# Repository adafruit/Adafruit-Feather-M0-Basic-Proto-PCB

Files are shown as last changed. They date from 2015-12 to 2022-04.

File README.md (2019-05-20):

## Adafruit Feather M0 Basic Proto PCB
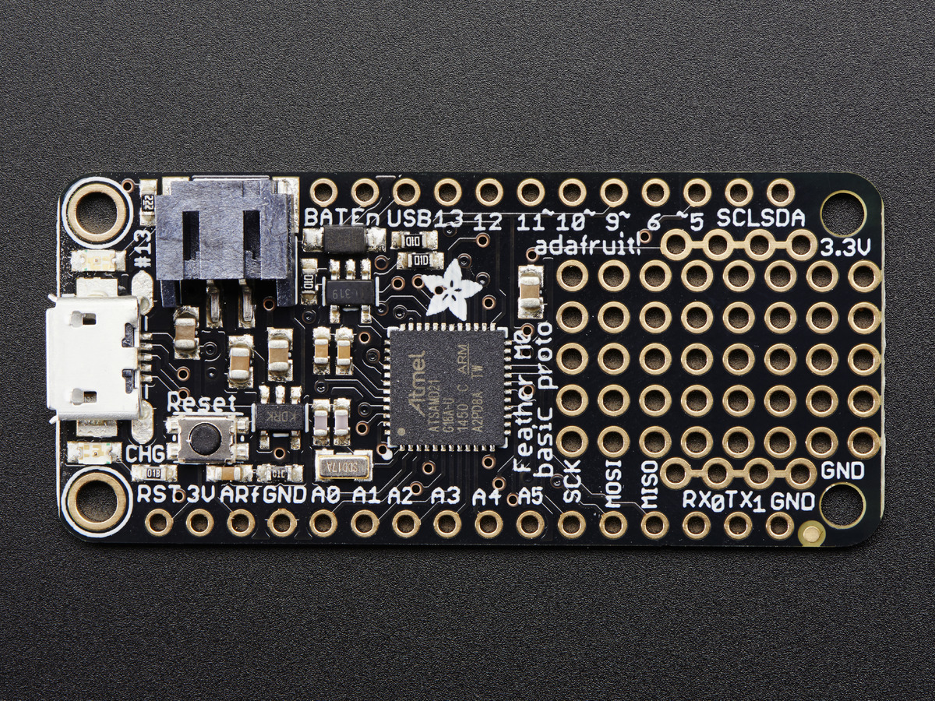
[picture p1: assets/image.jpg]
<a href="http://www.adafruit.com/products/2772"><br/>
Click here to purchase one from the Adafruit shop</a>

The Feather M0 has an ATSAMD21G18 ARM Cortex M0 processor, clocked at 48 MHz and at 3.3V logic, the same one used in the Arduino Zero. This chip has a whopping 256K of FLASH (8x more than the Atmega328 or 32u4) and 32K of RAM (16x as much)! This chip comes with built in USB so it has USB-to-Serial program & debug capability built in with no need for an FTDI-like chip.

To make it easy to use for portable projects, we added a connector for any of our 3.7V Lithium polymer batteries and built in battery charging. You don't need a battery, it will run just fine straight from the micro USB connector. But, if you do have a battery, you can take it on the go, then plug in the USB to recharge. The Feather will automatically switch over to USB power when its available. We also tied the battery thru a divider to an analog pin, so you can measure and monitor the battery voltage to detect when you need a recharge.

PCB files for the Adafruit Feather M0 Basic Proto. The format is EagleCAD schematic and board layout
- https://www.adafruit.com/product/2772

### License

Adafruit invests time and resources providing this open source design, please support Adafruit and open-source hardware by purchasing products from [Adafruit](https://www.adafruit.com)!

All text above must be included in any redistribution

Designed by Limor Fried/Ladyada for Adafruit Industries.
Creative Commons Attribution/Share-Alike, all text above must be included in any redistribution. 
See license.txt for additional information.

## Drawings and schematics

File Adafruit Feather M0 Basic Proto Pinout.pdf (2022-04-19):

# Adafruit Feather M0 Basic Proto

# https://www.adafruit.com/products/2772

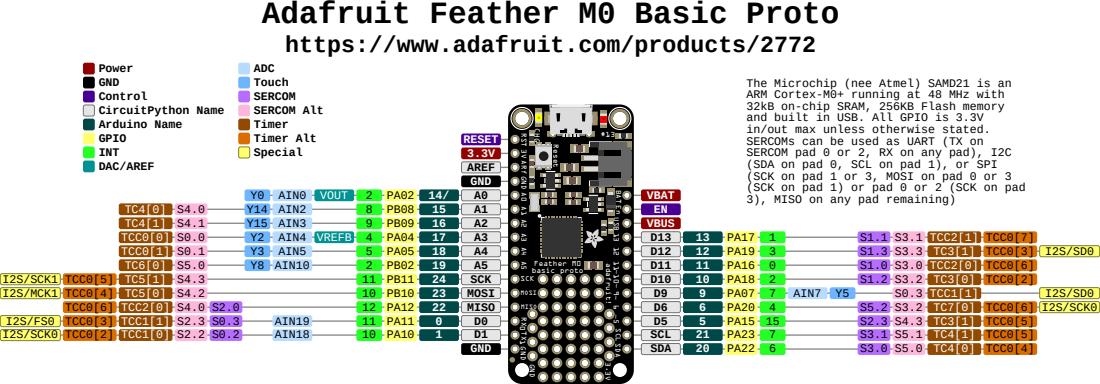
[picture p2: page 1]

The Microchip (nee Atmel) SAMD21 is an
ARM Cortex-M0+ running at 48 MHz with
32kB on-chip SRAM, 256KB Flash memory
and built in USB. All GPIO is 3.3V
in/out max unless otherwise stated.
SERCOMs can be used as UART (TX on
SERCOM pad 0 or 2, RX on any pad), I2C
(SDA on pad 0, SCL on pad 1), or SPI
(SCK on pad 1 or 3, MOSI on pad 0 or 3
(SCK on pad 1) or pad 0 or 2 (SCK on pad
3), MISO on any pad remaining)

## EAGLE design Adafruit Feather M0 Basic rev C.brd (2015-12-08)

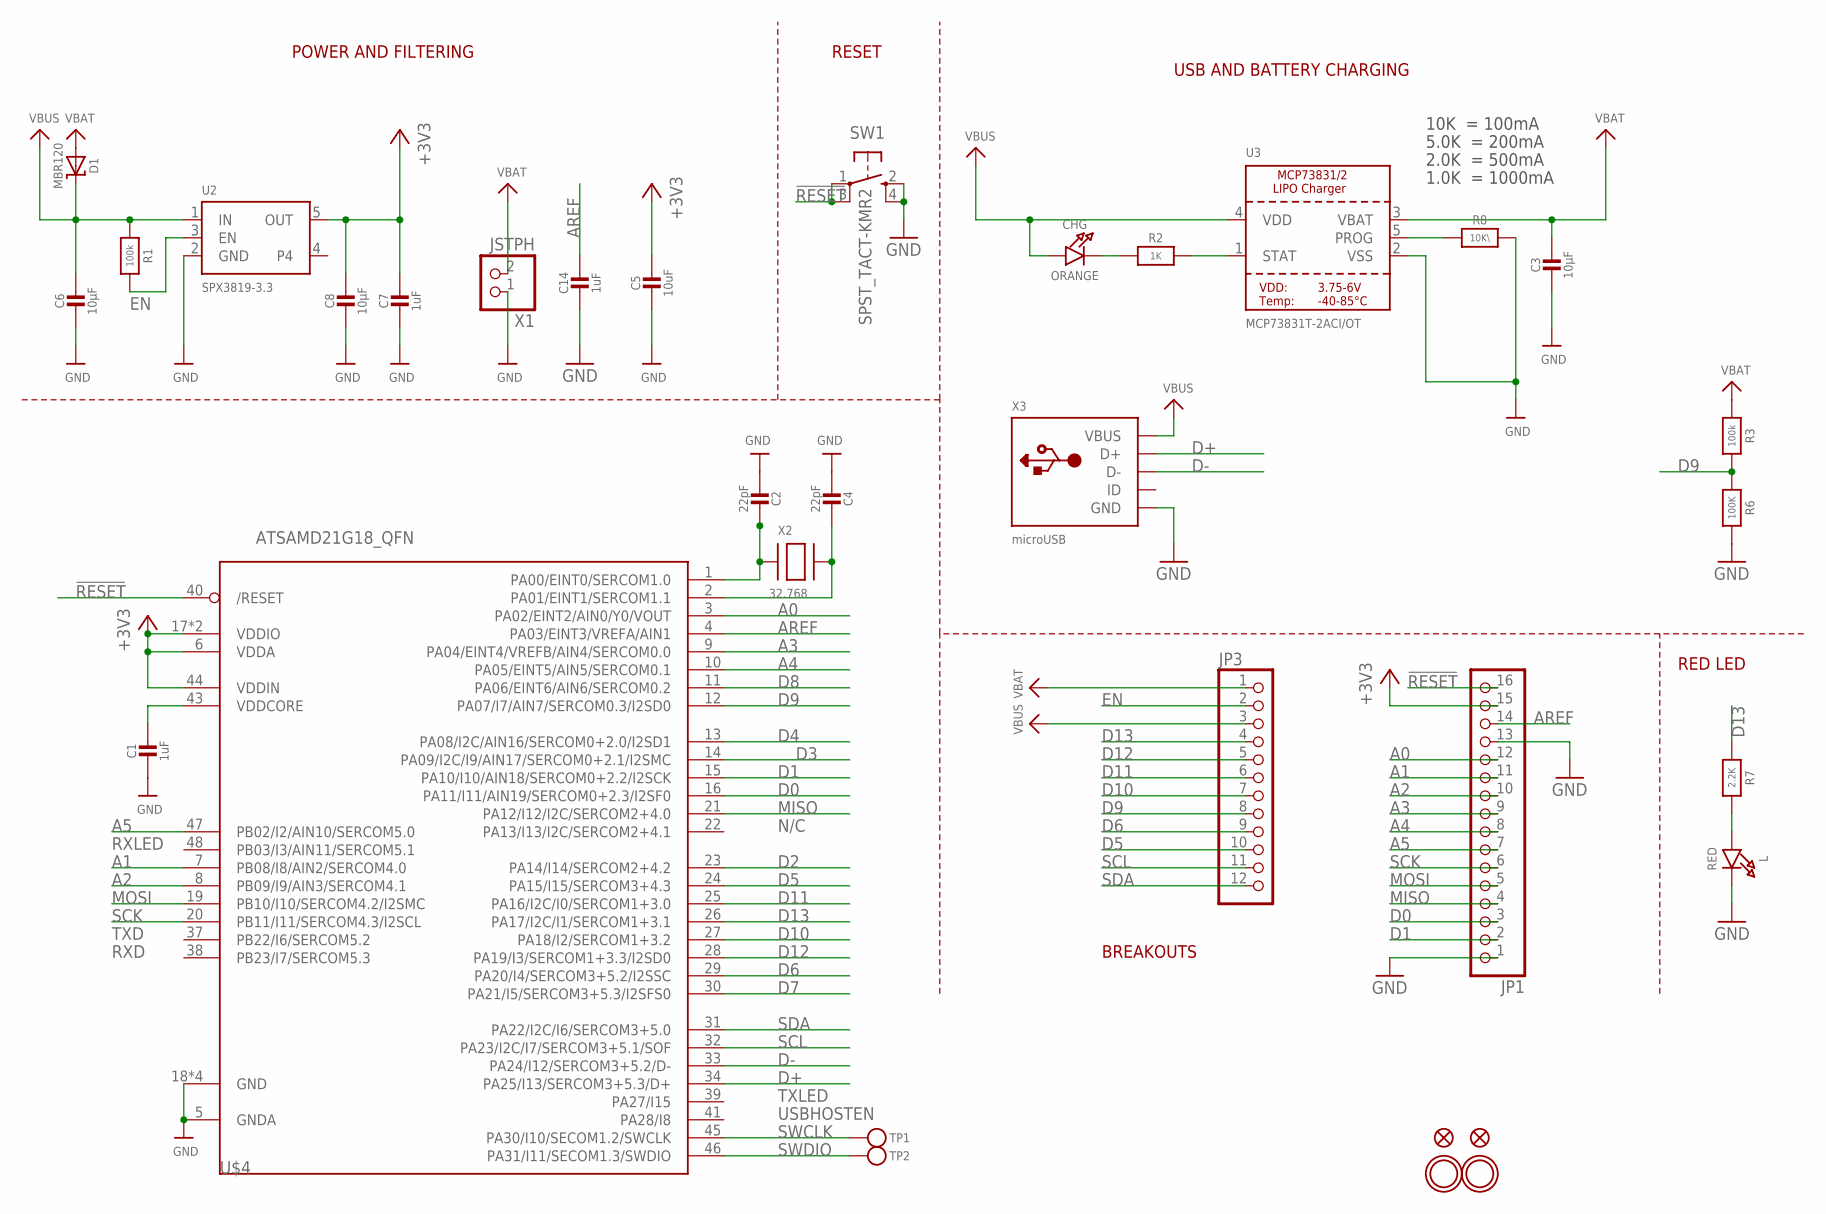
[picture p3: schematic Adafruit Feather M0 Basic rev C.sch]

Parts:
C1, C7, C14: 1uF; 0603-NO
C2, C4: 22pF; 0603-NO
C3, C6, C8: 10µF; 0805-NO
C5: 10uF; 0805-NO
CHG: ORANGE; CHIPLED_0805_NOOUTLINE
D1: MBR120; SOD-123
JP1: HEADER-1X16ROUND; 1X16_ROUND
JP3: HEADER-1X12; 1X12_ROUND
L: RED; CHIPLED_0805_NOOUTLINE
R1, R3: 100k; 0603-NO
R2: 1K; 0603-NO
R6: 100K; 0603-NO
R7: 2.2K; 0603-NO
R8: 10K\; 0603-NO
SW1: SPST_TACT-KMR2; KMR2
TP1, TP2: TESTPOINTROUND1.5MM; TESTPOINT_ROUND_1.5MM
U2: SPX3819-3.3; SOT23-5
U3: MCP73831T-2ACI/OT; SOT23-5
U$4: ATSAMD21G18_QFN; TQFN48_7MM
U$31, U$32: MOUNTINGHOLE2.5; MOUNTINGHOLE_2.5_PLATED
U$34, U$35: FIDUCIAL""; FIDUCIAL_1MM
X1: JSTPH; JSTPH2
X2: 32.768; XTAL3215
X3: microUSB; 4UCONN_20329_V2

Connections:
!RESET: JP1.16, SW1.1, SW1.3 (P1), U$4.40 (/RESET)
+3V3: C5.1, C7.1, C8.1, JP1.15, U2.5 (OUT), U$4.6 (VDDA), U$4.17 (VDDIO), U$4.36 (VDDIO), U$4.44 (VDDIN)
A0: JP1.12, U$4.3 (PA02/EINT2/AIN0/Y0/VOUT)
A1: JP1.11, U$4.7 (PB08/I8/AIN2/SERCOM4.0)
A2: JP1.10, U$4.8 (PB09/I9/AIN3/SERCOM4.1)
A3: JP1.9, U$4.9 (PA04/EINT4/VREFB/AIN4/SERCOM0.0)
A4: JP1.8, U$4.10 (PA05/EINT5/AIN5/SERCOM0.1)
A5: JP1.7, U$4.47 (PB02/I2/AIN10/SERCOM5.0)
AREF: C14.1, JP1.14, U$4.4 (PA03/EINT3/VREFA/AIN1)
D0: JP1.3, U$4.16 (PA11/I11/AIN19/SERCOM0+2.3/I2SF0)
D1: JP1.2, U$4.15 (PA10/I10/AIN18/SERCOM0+2.2/I2SCK)
D2: U$4.23 (PA14/I14/SERCOM2+4.2)
D3: U$4.14 (PA09/I2C/I9/AIN17/SERCOM0+2.1/I2SMC)
D4: U$4.13 (PA08/I2C/AIN16/SERCOM0+2.0/I2SD1)
D5: JP3.10, U$4.24 (PA15/I15/SERCOM3+4.3)
D6: JP3.9, U$4.29 (PA20/I4/SERCOM3+5.2/I2SSC)
D7: U$4.30 (PA21/I5/SERCOM3+5.3/I2SFS0)
D8: U$4.11 (PA06/EINT6/AIN6/SERCOM0.2)
D9: JP3.8, R3.2, R6.1, U$4.12 (PA07/I7/AIN7/SERCOM0.3/I2SD0)
D10: JP3.7, U$4.27 (PA18/I2/SERCOM1+3.2)
D11: JP3.6, U$4.25 (PA16/I2C/I0/SERCOM1+3.0)
D12: JP3.5, U$4.28 (PA19/I3/SERCOM1+3.3/I2SD0)
D13: JP3.4, R7.1, U$4.26 (PA17/I2C/I1/SERCOM1+3.1)
D+: U$4.34 (PA25/I13/SERCOM3+5.3/D+), X3.D+
D-: U$4.33 (PA24/I12/SERCOM3+5.2/D-), X3.D-
EN: JP3.2, R1.2, U2.3 (EN)
GND: C1.2, C2.2, C3.2, C4.2, C5.2, C6.2, C7.2, C8.2, C14.2, JP1.1, JP1.13, L.C, R6.2, R8.2, SW1.2 (S), SW1.4 (S1), U2.2 (GND), U3.2 (VSS), U$4.5 (GNDA), U$4.18 (GND), U$4.35 (GND), U$4.42 (GND), U$4.THERMAL (GND), X1.1, X3.BASE@1 (GND), X3.BASE@2 (GND), X3.GND, X3.SPRT@1 (GND), X3.SPRT@2 (GND), X3.SPRT@3 (GND), X3.SPRT@4 (GND)
MISO: JP1.4, U$4.21 (PA12/I12/I2C/SERCOM2+4.0)
MOSI: JP1.5, U$4.19 (PB10/I10/SERCOM4.2/I2SMC)
unnamed: CHG.C, R2.1
unnamed: L.A, R7.2
unnamed: R2.2, U3.1 (STAT)
unnamed: R8.1, U3.5 (PROG)
unnamed: C2.1, U$4.1 (PA00/EINT0/SERCOM1.0), X2.P$1
unnamed: C4.1, U$4.2 (PA01/EINT1/SERCOM1.1), X2.P$2
SCK: JP1.6, U$4.20 (PB11/I11/SERCOM4.3/I2SCL)
SCL: JP3.11, U$4.32 (PA23/I2C/I7/SERCOM3+5.1/SOF)
SDA: JP3.12, U$4.31 (PA22/I2C/I6/SERCOM3+5.0)
SWCLK: TP1.P$1, U$4.45 (PA30/I10/SECOM1.2/SWCLK)
SWDIO: TP2.P$1, U$4.46 (PA31/I11/SECOM1.3/SWDIO)
VBAT: C3.1, D1.A, JP3.1, R3.1, U3.3 (VBAT), X1.2
VBUS: C6.1, CHG.A, D1.C, JP3.3, R1.1, U2.1 (IN), U3.4 (VDD), X3.VBUS
VDDCORE: C1.1, U$4.43 (VDDCORE)

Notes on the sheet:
POWER AND FILTERING
RESET
10K = 100mA
5.0K = 200mA
2.0K = 500mA
1.0K = 1000mA
N/C
TXLED
USBHOSTEN
RXLED
TXD
RXD
USB AND BATTERY CHARGING
BREAKOUTS
RED LED

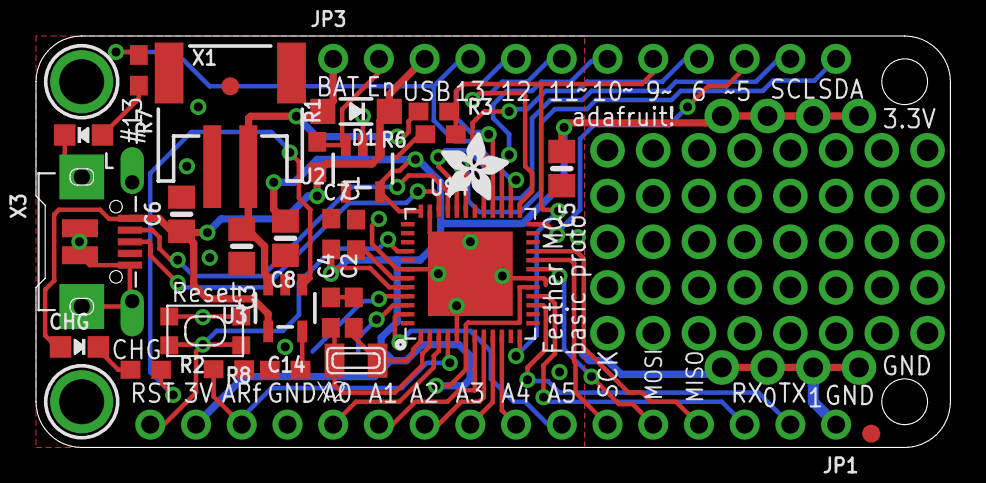
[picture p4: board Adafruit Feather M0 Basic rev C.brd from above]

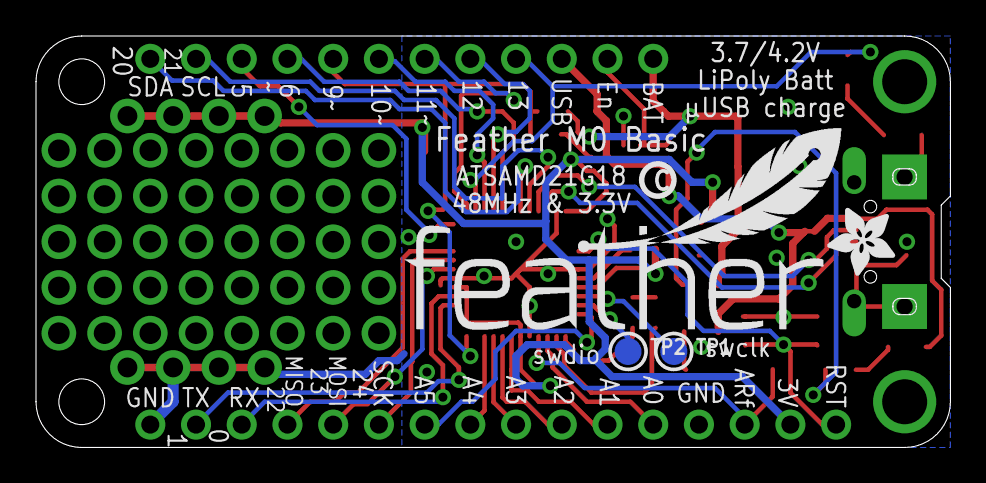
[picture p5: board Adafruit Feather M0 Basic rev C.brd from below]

Board: 2 copper layers, 50.8 x 22.9 mm, 37 parts (5 on the bottom side), 38 nets.

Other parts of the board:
U$7, U$12: ADAFRUIT_3.5MM
U$9: FEATHERLOGO
U$13: PCBFEAT-REV-040

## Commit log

2015-12-08 init pcb
    [Adafruit Feather M0 Basic rev C.brd, Adafruit Feather M0 Basic rev C.sch]
2016-01-12 bootloader for atsamd using adafruit vid/pid & pulsing LED

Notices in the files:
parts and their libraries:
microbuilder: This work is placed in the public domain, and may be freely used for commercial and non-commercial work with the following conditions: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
